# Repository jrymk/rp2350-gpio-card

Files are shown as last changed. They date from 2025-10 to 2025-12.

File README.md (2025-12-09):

# rp2350-gpio-card
Expansion Card circuit based on RP2350 for Framework mainboards providing GPIO to the computer. Circuit is based on [Expansion Card template](https://github.com/FrameworkComputer/ExpansionCards) and [RP2350A Minimal board](https://datasheets.raspberrypi.com/rp2350/hardware-design-with-rp2350.pdf). Designed in [KiCad](https://www.kicad.org/). It got produced and assembled. Its fully functional. A 3D case for the card is made by XenoCow and [its files are available on Printables.com](https://www.printables.com/model/1445941-framework-expansion-card-case-for-typec-950-arp24).

## Gallery
* Real photo of card with TYPEC-950-ARP24 produced by NextPCB
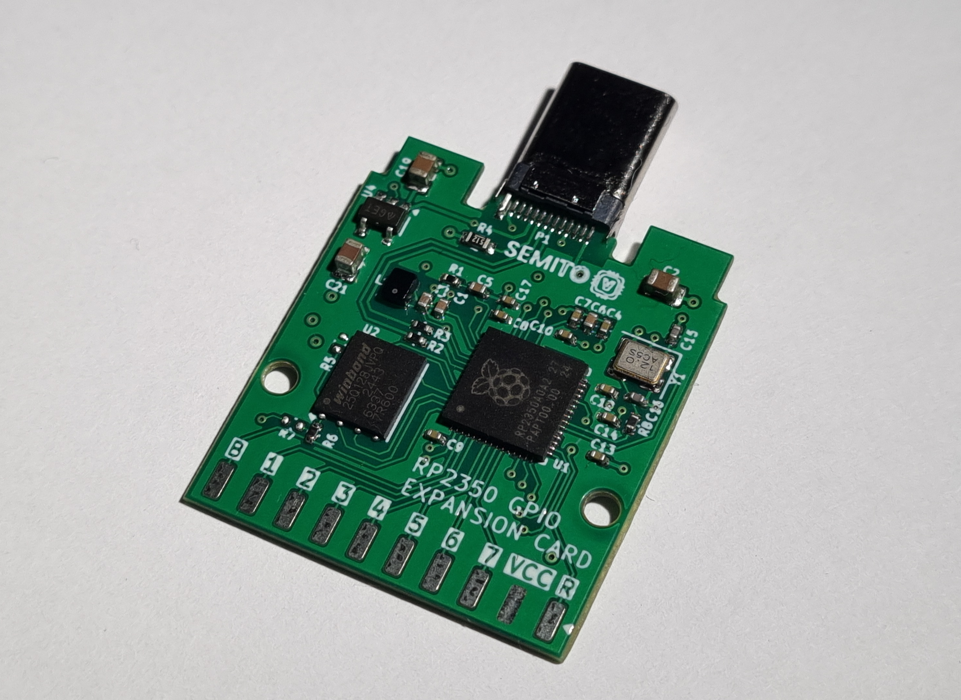
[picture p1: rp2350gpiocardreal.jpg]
RP2350 GPIO Card real


* Render of card with Molex 1054440011 (Framework template)
RP2350 GPIO Card prototype render
RP2350 GPIO Card prototype render

* Render of card with TYPEC-950-ARP24 (NextPCB template)
RP2350 GPIO Card prototype render
RP2350 GPIO Card prototype render

## GPIO
### Front
| Label | Name | SPI | UART | I2C | ADC |
| :---- | :----- | :--- | :--- | :--- | :-- |
| 0 | GPIO0  | SPI0 RX | UART0 TX | I2C0 SDA | |
| 1 | GPIO1  | SPI0 CSn  | UART0 RX | I2C0 SCL | |
| 2 | GPIO2  | SPI0 SCK  | | I2C1 SDA | |
| 3 | GPIO3  | SPI0 TX | | I2C1 SCL | |
| 4 | GPIO4  | SPI0 RX | UART1 TX | I2C0 SDA | |
| 5 | GPIO5  | SPI0 CSn  | UART1 RX | I2C0 SCL | |
| 6 | GPIO6  | SPI0 SCK  | | I2C1 SDA | |
| 7 | GPIO7  | SPI0 TX | | I2C1 SCL | |
| VCC | 3.3v | | | | |
| R | Reset  | | | | |

### Back
| Label | Name | SPI | UART | I2C | ADC |
| :---- | :----- | :--- | :--- | :--- | :---- |
| 29 | GPIO29 | | | | ADC3  |
| 28 | GPIO28 | | | | ADC2  |
| 27 | GPIO27 | | | I2C1 SDL | ADC1  |
| G | Ground | | | | |
| 13 | GPIO13 | SPI1 CSN  | UART0 RX | I2C0 SCL | |
| 12 | GPIO12 | SPI1 RX | UART0 TX | I2C0 SDA | |
| 11 | GPIO11 | SPI1 TX | | I2C1 SCL | |
| 10 | GPIO10 | SPI1 SCK  | | I2C1 SDA | |
| 9 | GPIO9  | SPI1 CSn  | UART1 RX | I2C0 SCL | |
| B | Boot | | | | |

## License
Designed by: [Tan Siret Akıncı](https://github.com/tansiret).
Schematics and footprint are licensed with [CC BY 4.0](LICENSE).
Politecnico di Torino name used in this project is © 2025 Politecnico di Torino. The project is sponsored by © 2025 [DeepComputing](https://deepcomputing.io/) and © 2025 [NextPCB](https://www.nextpcb.com/).
The project has been certified by [OSHWA](https://oshwa.org/) as Open Source Hardware (UID: [IT000024](https://certification.oshwa.org/it000024.html)).
</br>
<a href="https://certification.oshwa.org/it000024.html">
   
</a>

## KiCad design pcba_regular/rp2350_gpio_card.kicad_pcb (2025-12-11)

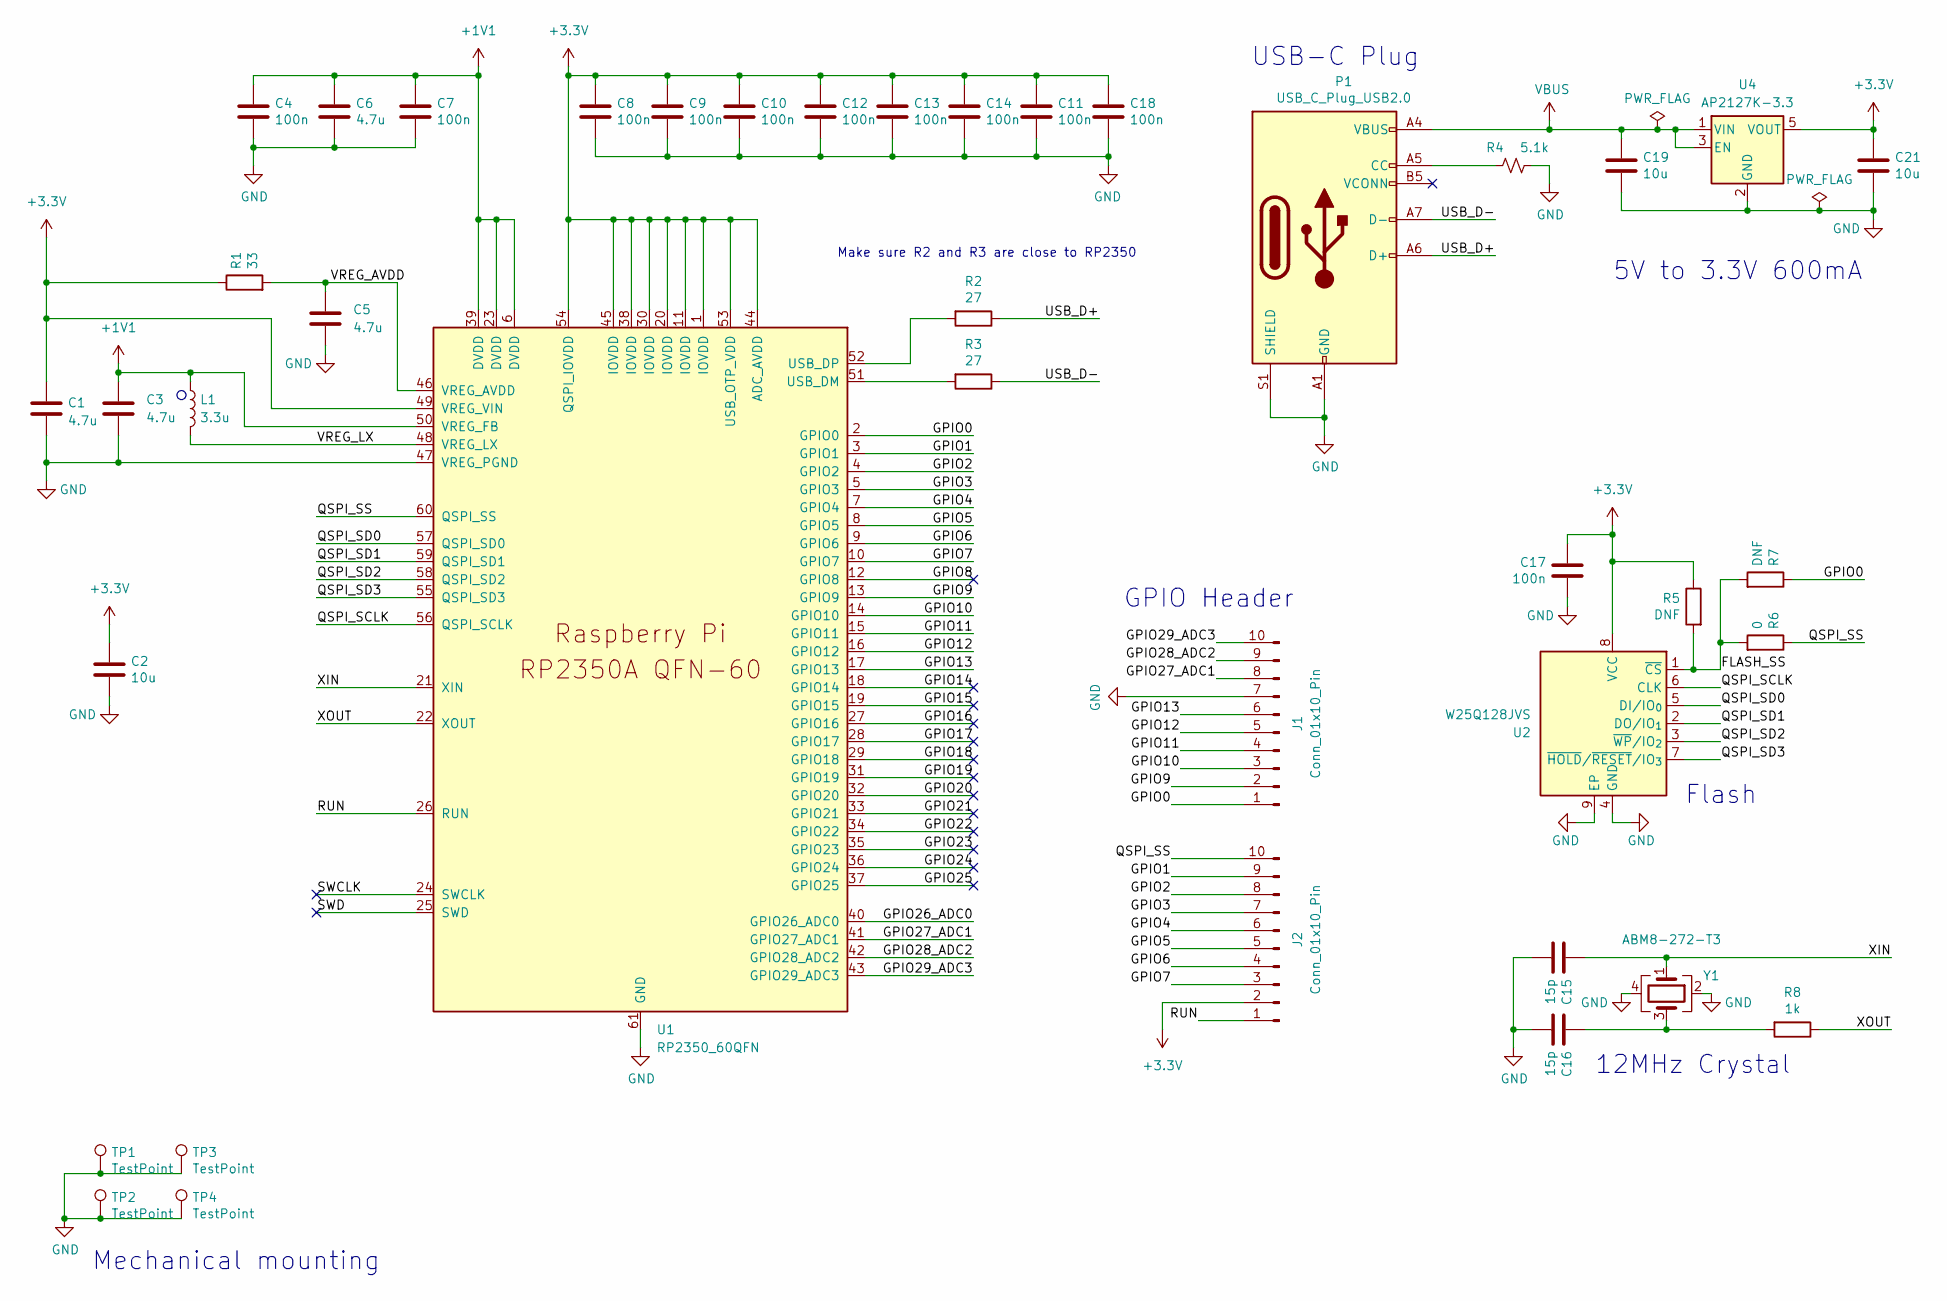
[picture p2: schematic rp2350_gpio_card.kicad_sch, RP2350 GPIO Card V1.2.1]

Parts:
C1, C3: 4.7u; C_0402_1005Metric_small_pads
C2, C19, C21: 10u; C_0805_2012Metric
C4, C7, C8, C9, C10, C11, C12, C13, C14, C17, C18: 100n; C_0402_1005Metric
C5, C6: 4.7u; C_0402_1005Metric
C15, C16: 15p; C_0402_1005Metric
J1, J2: Conn_01x10_Pin; Custom_Harwin_M20-89010xx_1x10_P2.54mm_Horizontal
L1: 3.3u; L_pol_2016
P1: USB_C_Plug_USB2.0; USB_C_Plug_Molex_105444
R1: 33; R_0402_1005Metric
R2, R3: 27; R_0402_1005Metric
R4: 5.1k; R_0402_1005Metric
R5, R7: DNF; R_0402_1005Metric
R6: 0; R_0402_1005Metric
R8: 1k; R_0402_1005Metric
TP1, TP2, TP3, TP4: TestPoint; TestPoint_Pad_1.5x1.5mm
U1: RP2350_60QFN; RP2350-QFN-60-1EP_7x7_P0.4mm_EP3.4x3.4mm_ThermalVias
U2: W25Q128JVS; WSON-8-1EP_6x5mm_P1.27mm_EP3.4x4.3mm
U4: AP2127K-3.3; SOT-23-5
Y1: ABM8-272-T3; Crystal_SMD_3225-4Pin_3.2x2.5mm

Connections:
+1V1: C3.1, C4.1, C6.1, C7.1, L1.1, U1.6 (DVDD), U1.23 (DVDD), U1.39 (DVDD), U1.50 (VREG_FB)
+3.3V: C1.1, C2.1, C8.1, C9.1, C10.1, C11.1, C12.1, C13.1, C14.1, C17.1, C18.1, C21.1, J2.2, R1.1, R5.1, U1.1 (IOVDD), U1.11 (IOVDD), U1.20 (IOVDD), U1.30 (IOVDD), U1.38 (IOVDD), U1.44 (ADC_AVDD), U1.45 (IOVDD), U1.49 (VREG_VIN), U1.53 (USB_OTP_VDD), U1.54 (QSPI_IOVDD), U2.8 (VCC), U4.5 (VOUT)
/FLASH_SS: R5.2, R6.2, R7.2, U2.1 (~CS)
/GPIO0: J1.1, R7.1, U1.2 (GPIO0)
/GPIO1: J2.9, U1.3 (GPIO1)
/GPIO2: J2.8, U1.4 (GPIO2)
/GPIO3: J2.7, U1.5 (GPIO3)
/GPIO4: J2.6, U1.7 (GPIO4)
/GPIO5: J2.5, U1.8 (GPIO5)
/GPIO6: J2.4, U1.9 (GPIO6)
/GPIO7: J2.3, U1.10 (GPIO7)
/GPIO8: U1.12 (GPIO8)
/GPIO9: J1.2, U1.13 (GPIO9)
/GPIO10: J1.3, U1.14 (GPIO10)
/GPIO11: J1.4, U1.15 (GPIO11)
/GPIO12: J1.5, U1.16 (GPIO12)
/GPIO13: J1.6, U1.17 (GPIO13)
/GPIO14: U1.18 (GPIO14)
/GPIO15: U1.19 (GPIO15)
/GPIO16: U1.27 (GPIO16)
/GPIO17: U1.28 (GPIO17)
/GPIO18: U1.29 (GPIO18)
/GPIO19: U1.31 (GPIO19)
/GPIO20: U1.32 (GPIO20)
/GPIO21: U1.33 (GPIO21)
/GPIO22: U1.34 (GPIO22)
/GPIO23: U1.35 (GPIO23)
/GPIO24: U1.36 (GPIO24)
/GPIO25: U1.37 (GPIO25)
/GPIO26_ADC0: U1.40 (GPIO26_ADC0)
/GPIO27_ADC1: J1.8, U1.41 (GPIO27_ADC1)
/GPIO28_ADC2: J1.9, U1.42 (GPIO28_ADC2)
/GPIO29_ADC3: J1.10, U1.43 (GPIO29_ADC3)
/QSPI_SCLK: U1.56 (QSPI_SCLK), U2.6 (CLK)
/QSPI_SD0: U1.57 (QSPI_SD0), U2.5 (DI/IO_{0})
/QSPI_SD1: U1.59 (QSPI_SD1), U2.2 (DO/IO_{1})
/QSPI_SD2: U1.58 (QSPI_SD2), U2.3 (~WP/IO_{2})
/QSPI_SD3: U1.55 (QSPI_SD3), U2.7 (~HOLD/~RESET/IO_{3})
/QSPI_SS: J2.10, R6.1, U1.60 (QSPI_SS)
/RUN: J2.1, U1.26 (RUN)
/SWCLK: U1.24 (SWCLK)
/SWD: U1.25 (SWD)
/USB_D+: P1.A6 (D+), R2.1
/USB_D-: P1.A7 (D-), R3.1
/VREG_AVDD: C5.1, R1.2, U1.46 (VREG_AVDD)
/VREG_LX: L1.2, U1.48 (VREG_LX)
/XIN: C15.1, U1.21 (XIN), Y1.1
/XOUT: R8.1, U1.22 (XOUT)
GND: C1.2, C2.2, C3.2, C4.2, C5.2, C6.2, C7.2, C8.2, C9.2, C10.2, C11.2, C12.2, C13.2, C14.2, C15.2, C16.2, C17.2, C18.2, C19.2, C21.2, J1.7, P1.A1 (GND), P1.A12 (GND), P1.B1 (GND), P1.B12 (GND), P1.S1 (SHIELD), R4.2, TP1.1, TP2.1, TP3.1, TP4.1, U1.47 (VREG_PGND), U1.61 (GND), U2.4 (GND), U2.9 (EP), U4.2 (GND), Y1.2, Y1.4
unnamed: C16.1, R8.2, Y1.3
unnamed: P1.A5 (CC), R4.1
unnamed: R3.2, U1.51 (USB_DM)
unnamed: R2.2, U1.52 (USB_DP)
VBUS: C19.1, P1.A4 (VBUS), P1.A9 (VBUS), P1.B4 (VBUS), P1.B9 (VBUS), U4.1 (VIN), U4.3 (EN)

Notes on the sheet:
GPIO Header
5V to 3.3V 600mA
USB-C Plug
Mechanical mounting
12MHz Crystal
Flash
Make sure R2 and R3 are close to RP2350

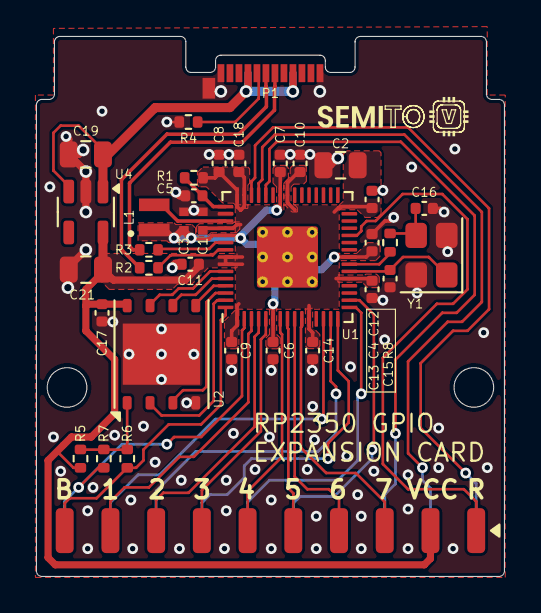
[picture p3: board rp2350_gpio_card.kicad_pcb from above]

Board: 2 copper layers, 26.0 x 30.0 mm, 38 parts (1 on the bottom side), 38 nets.

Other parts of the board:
H1, H2: MountingHole; MountingHole_2.2mm_M2

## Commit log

2025-12-10 optimized PCB layout
    [rp2350_gpio_card.kicad_pcb, rp2350_gpio_card.kicad_sch]
2025-12-10 optimized back gnd plane
    [rp2350_gpio_card.kicad_pcb]
2025-12-10 added open hardware graphics back
    [rp2350_gpio_card.kicad_pcb]
2025-12-10 clean up
    [rp2350_gpio_card.kicad_pcb]
2025-12-11 fix DRC errors and increase clearances
    [rp2350_gpio_card.kicad_pcb]

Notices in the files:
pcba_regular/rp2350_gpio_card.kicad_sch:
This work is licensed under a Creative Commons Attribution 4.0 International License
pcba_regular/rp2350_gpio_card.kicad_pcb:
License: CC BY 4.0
